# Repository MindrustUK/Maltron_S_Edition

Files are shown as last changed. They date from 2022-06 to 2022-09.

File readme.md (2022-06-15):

# Maltron - S Edition

** THIS IS A WORK IN PROGRESS, EXPECT BUGS AND DEBUGGING OPTIONS TO BE SET**

This repository contains historical documentation and instructions for creating a STM32 Black Pill based Keyboard
controller for Maltron Right Handed Keyboards running the open source QMK Firmware.

I'm hoping to get the new firmware into QMK mainstream at some stage in the future.

If anyone has any feedback please feel free to open an issue on the GitHub tracker, and I'll respond to you when I can.

All files can be found in their respective subdirectories as follows:
- EasyEDA Outfiles: This contains; Easy EDA, Altium, Gerber and SVG outputs of the Schematic and PCB design for the 
Maltron compatible STM32 Based controller.
- QMK Firmware: The QMK Firmware for the Maltron S Edition keyboard. This is a work in progress and not final yet.
- FreeCAD - PCB Stand Offs: This contains some simple PCB Stand-Offs that can be glued to the existing Maltron case's
baseplate. These are designed to use M2 self taping wood screws.
- Pictures: Pictures of the build for the historical document.

## Circuit notes
- All diodes are 1n4148
- Resistors for LEDS (R3-R10) are 100 Ohm
- Resistors for I2C Pull up (R1, R2) are 10K Ohm

## FreeCAD Notes
- Screws for PCB mounting are M2 Self Tapping Wood screws - Pan Head type.

## QMK Firmware Notes
- Large portions of this code were adapted from
[https://github.com/zvecr/qmk_firmware/blob/feature/ergodone_ctpc/keyboards/ktec/ergodone/matrix.c](https://github.com/zvecr/qmk_firmware/blob/feature/ergodone_ctpc/keyboards/ktec/ergodone/matrix.c)
so all credit to this user for their work. This helped me massively with the MCP23018 I/O Expander.
- Setup QMK as per [https://docs.qmk.fm/#/newbs_getting_started](https://docs.qmk.fm/#/newbs_getting_started)
- copy *mindrustuk* from the QMK Firmware directory to *keyboards/* in the QMK installation path
- NOTE: On first flash the STM32 Black Pill will need to be put into bootloader mode, do this by:
  - pushing and holding the `reset` button
  - then hold the `boot0` button
  - release the `reset` button
  - then release the `boot0` button. 
  - The device should now be in the bootloader mode ready to be flashed.
- compile using the following command ```qmk compile -kb mindrustuk/maltron_s_edition -km default```
- flash with the following command ```qmk flash -kb mindrustuk/maltron_s_edition -km default```
- Note: The firmware has `bootmagic` enabled. Any subsequent need to flash can be done by holding the `esc` key while
plugging in the keyboard, doing this will force the keyboard into bootloader mode on boot.
- Note: Debugging is currently enabled on this keyboard and output can be seen with ```qmk console -l```

## Miscellaneous Keyboard details
- The keyboard has four layers, these have not been fully implemented yet:
  - Layer 1: English
  - Layer 2: Numeric Pad
  - Layer 3: German
  - Layer 4: Media Keys

- Attempts have been made to preserve / replicate "one shot" behaviour and sticky keys on the Maltron keyboard. Please
see the source code for details on these.

- Bootmagic is set to use the escape key to flash firmware on boot, this could be re-mapped if desired:
  ```
  // Hold ESC on start up to boot into bootloader mode
  #define BOOTMAGIC_LITE_ROW 0
  #define BOOTMAGIC_LITE_COLUMN 14
  ```

## History
For a history of how this project started and evolved please see [history.md](history.md)

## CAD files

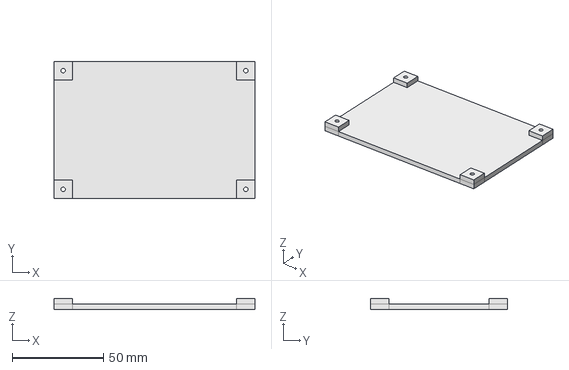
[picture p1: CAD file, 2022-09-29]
Controller Mount Mk2.FCStd
110.0 x 75.0 x 6.00 mm

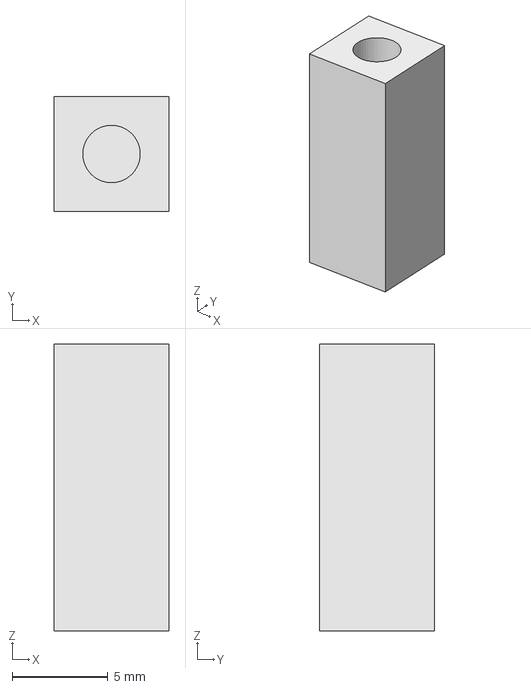
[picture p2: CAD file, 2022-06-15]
FreeCad - PCB Stand Offs/Maltron PCB Mounts.FCStd
6.00 x 6.00 x 15.0 mm

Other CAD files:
Controller Mount Mk2-Cut003.stl

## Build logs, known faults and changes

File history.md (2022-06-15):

# Maltron - S Edition - The history

This project started when a hemiplegic user with a few different versions / variants of the Maltron Single handed 
(right side) keyboard, was having trouble with slightly different layouts across the keyboards they used at various
sites.

Some of these were the current (as of time of writing) keyboards sold by Maltron, Others were older PS/2 style units.

The user wanted to achieve as close parity between all units in terms of the keyboard's layout. To this end, the older
PS/2 Keyboards would be converted to USB using the [QMK Firmware](https://qmk.fm/) to cover many of the features (sticky
keys, layers etc.) that were built into these units.  This would also mean the keymap could be changed to bring them
into line with the current layout for the keyboard found here:
[https://www.maltron.com/united-kingdom.html](https://www.maltron.com/united-kingdom.html), specifically the
**RS10N1X-UK** model.

When asking for assistance on Reddit in understanding how QMK worked with IO Expanders, a user asked that I document the
process, and thus this repository was created.

This repository contains the following materials:
- Docuemtnation on the process
- Circuit Diagrams
- Gerber files
- Easy EDA files
- The Maltron S Edition specific files for generating a compatible QMK Firmware.

A comparison of two of the keyboard types can be seen in the following pictures:

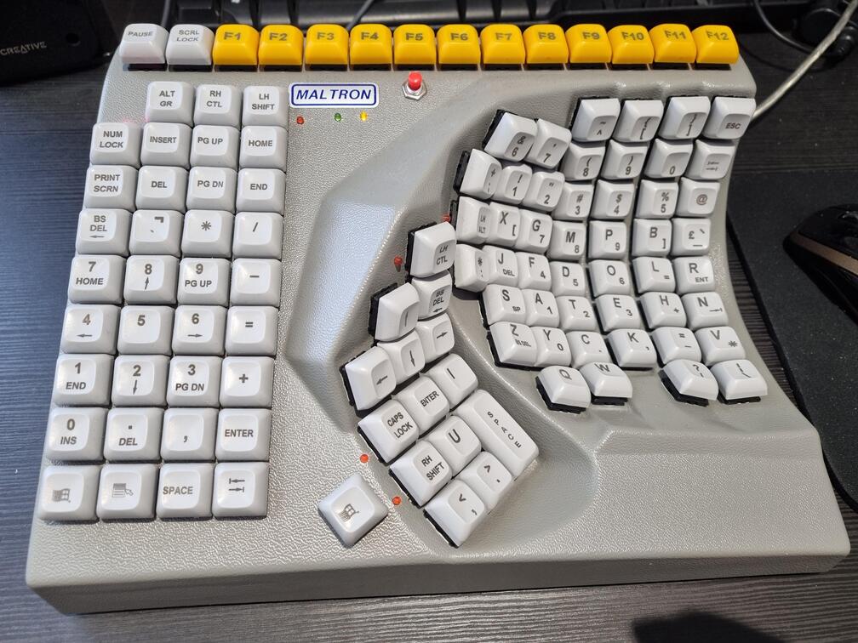
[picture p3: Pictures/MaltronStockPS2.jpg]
Maltron Stock PS2 Keyboard

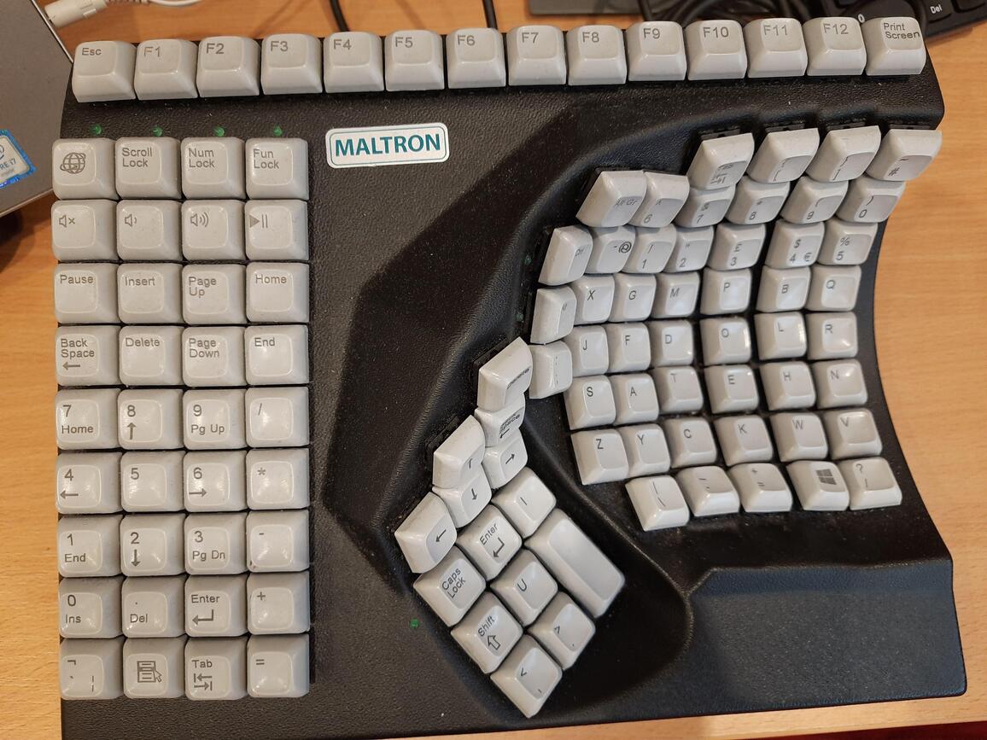
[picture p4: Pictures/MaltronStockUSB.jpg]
Maltron Stock USB Keyboard


## The process

The first step was to understand the anatomy of they device, on the PS/2 units that I'd be working on some searching
revealed the matrix in use was an 8 row, 16 column matrix, further use of a multi meter and physical inspection showed
8 leds in use with 8 diodes on the rows for anti ghosting.

As I wasn't confident at this stage and wanted a back out plan before committing I decided to remove the factory IDC
transition connector and replace it with a 34 pin IDC connector allowing for controller replacements in the future along
with easy prototyping and most of all a way to roll back if anything proved to be beyond reasonable.

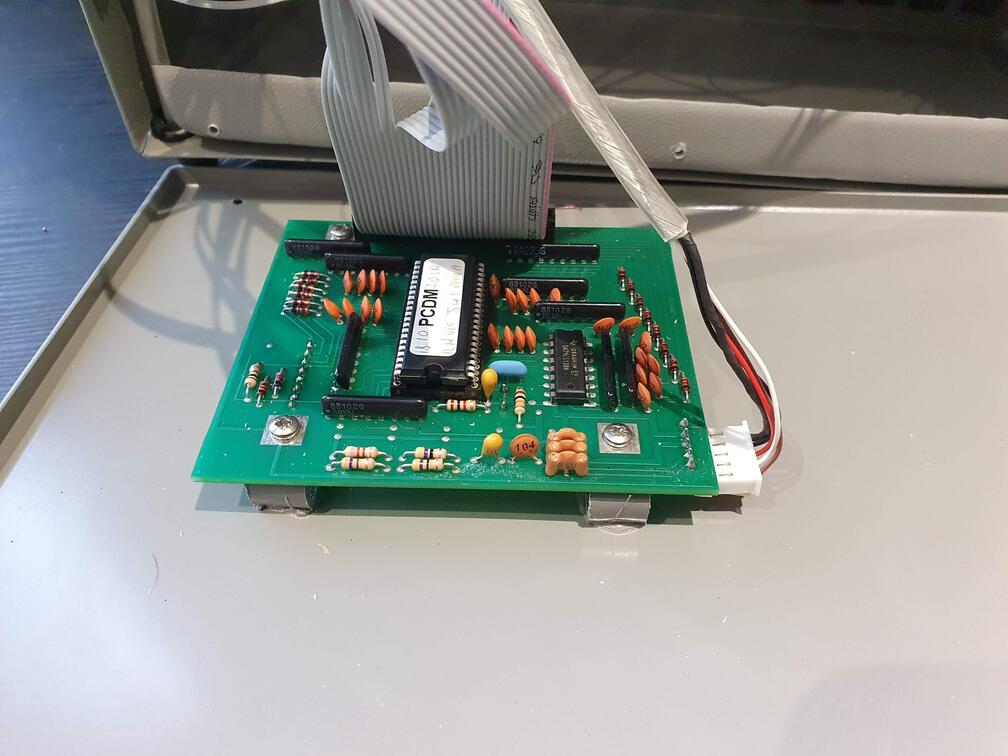
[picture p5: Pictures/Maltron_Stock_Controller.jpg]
Maltron Stock Controller


The next step was to select a controller and start experimenting. I had faith in the QMK project as I had a friend who
had been raving about his custom-built keyboards for a while. I had 32 pins worth of Input / Output to deal with.
The larger Teensy series controllers proved expensive and hard to source in the UK and also offered less I/O than
competitors. The Raspberry Pi Pico was also evaluated and passed on for reasons I can't quite remember. I then found the
STM 32 - Black Pill module. This had USB-C, plenty of I/O, loads of memory and more than enough CPU power and
importantly was supported by qmk. However, I would shortly find out much of the I/O was unusable.

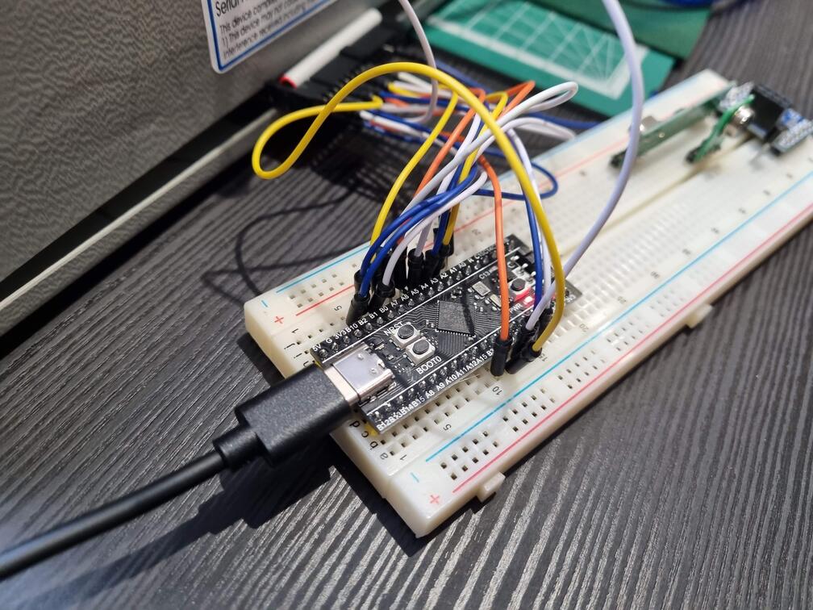
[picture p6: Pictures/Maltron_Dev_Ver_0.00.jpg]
Maltron S Edition Dev 0.00 Controller


Early test with the QMK firmware was to build the simplest keyboard possible and get the matrix running. I managed to
get all rows and columns working and then started getting strange behaviour as I expanded, such as the controller not
starting, Errors with flashing and so on. I discovered after more study of documentation and searching Reddit that;
pins A9, A11 and A12 are all attached to USB, A10 can be used as an input but requires a pull-up resistor and B2 is a
reserved for use in the bootloader functionality. After some research and understanding the attributes of each of these
pins I realised no matter what I did on this module, I'd have to add an I/O expander.

The I2C bus is well known and widely supported, also thanks to some friendly pointers on Reddit and investigating the
Ergodox keyboard documentation and QMK Firmware, I found that the Microchip MCP23018 would fit my use case.

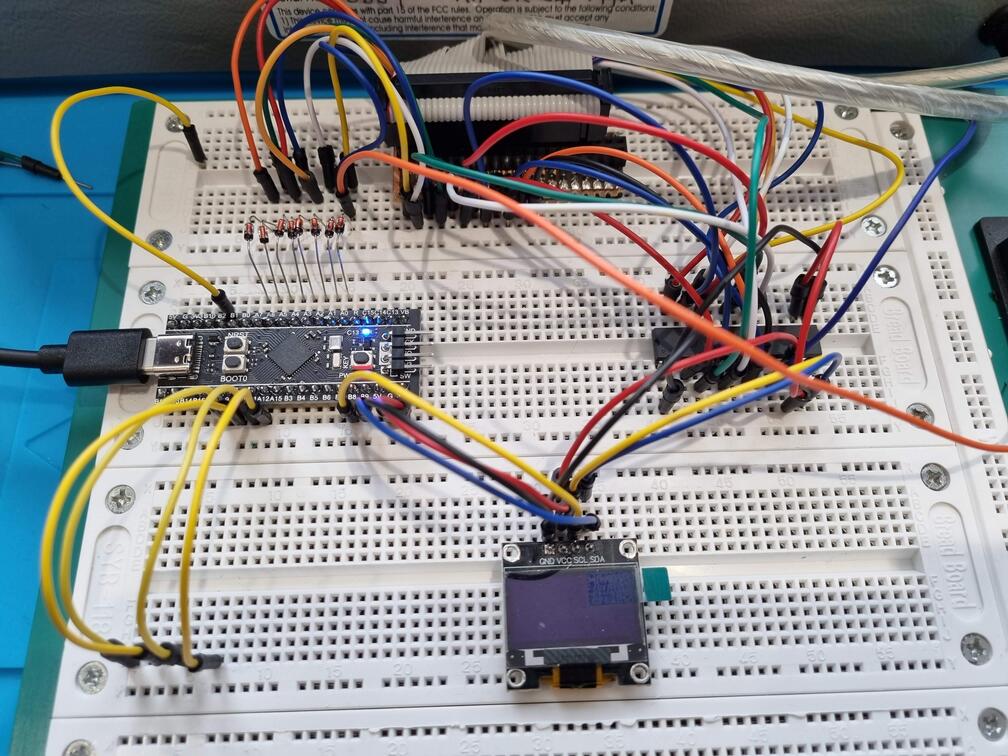
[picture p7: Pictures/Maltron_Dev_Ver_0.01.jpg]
Maltron S Edition Dev 0.01 Controller


The next challenge would be software, thankfully I got lucky and during my prototyping, the QMK project matured and the
I2C support for the MCP23018 became natively available. I also found someone who had ported their version of the
firmware to the native driver:
[ergodone](https://github.com/zvecr/qmk_firmware/blob/feature/ergodone_ctpc/keyboards/ktec/ergodone/matrix.c)
I also added a SSD1306 OLED to the project as a temporary measure to give me some easy visual output as I continued 
work on getting the I2C support added. After coming to understand the firmware, adding debugging and generally maturing
the project, I removed the OLED support. This could be added back at anytime should anyone desire it.

I now had an I2C expander on all the columns of the keyboard, the LEDs and rows being driven from the STM32 Black Pill
controller and a basic keymap working. I now moved from Breadboard Development to a Soldered Prototype.

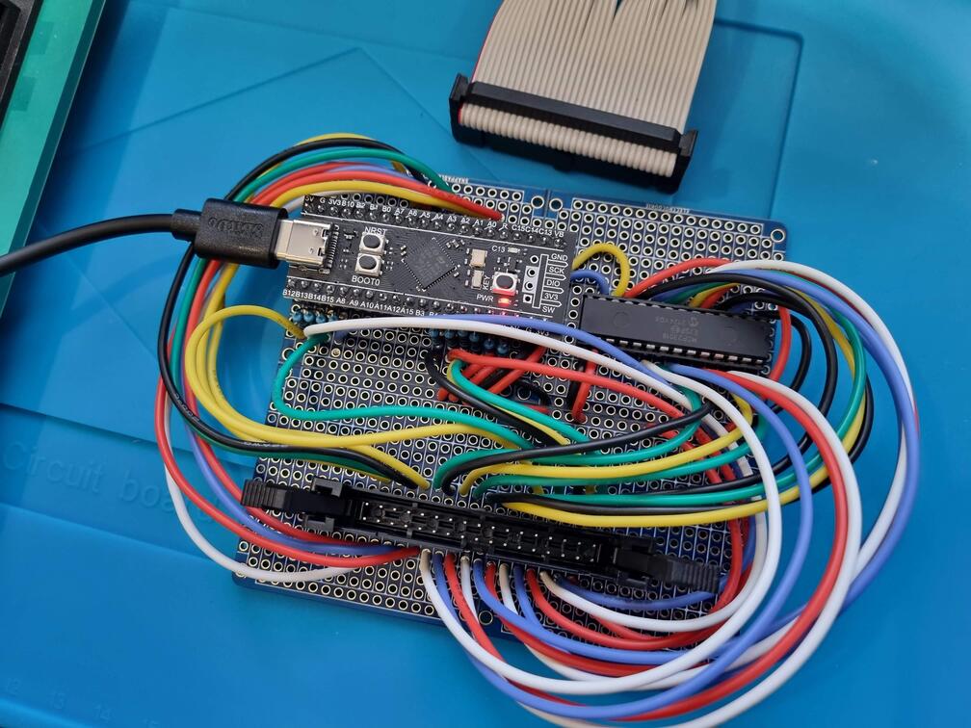
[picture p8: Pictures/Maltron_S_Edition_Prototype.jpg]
Maltron S Edition Prototype Controller


After an evening with the soldering iron I had a prototype version of the controller. More revisions of the software, 
more tweaking, getting sticky keys working, and adding layer support was done. Shortly after this process it was time to
move to the "production" version of the design. And after an amazingly quick session in [EasyEDA](https://easyeda.com/),
I had the following diagram:

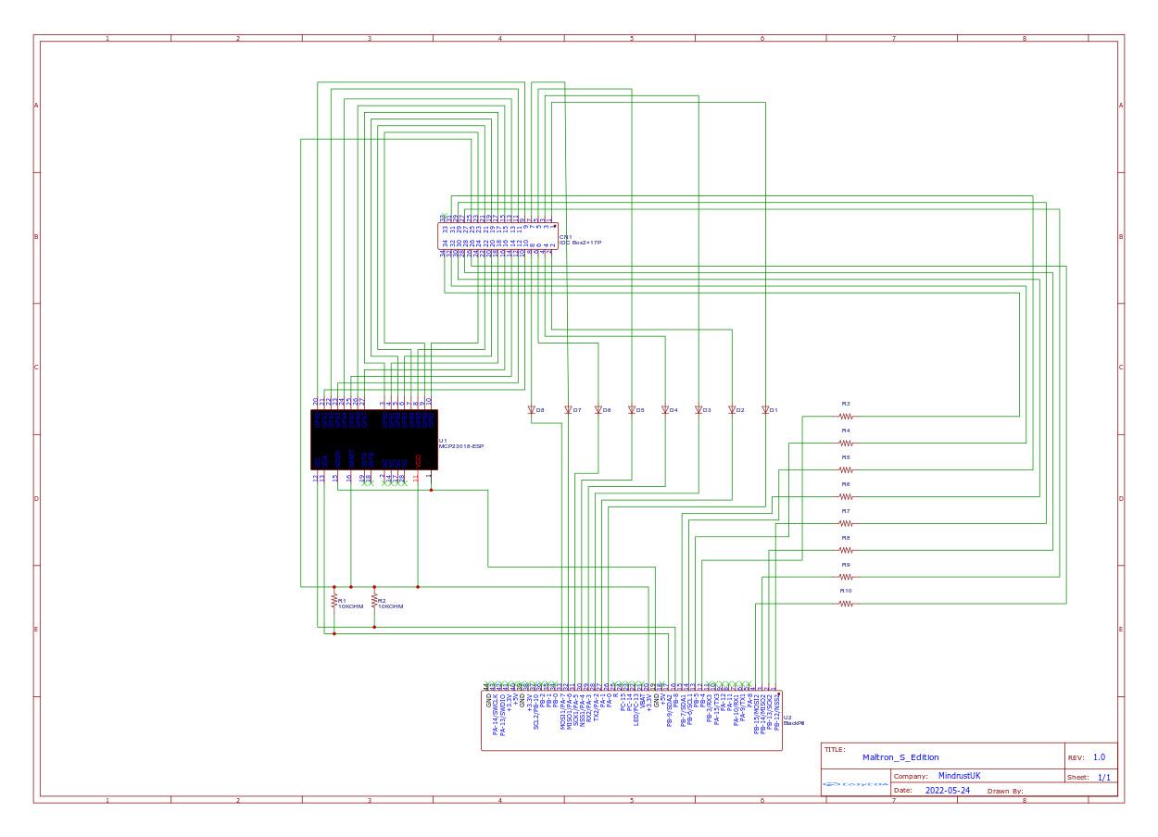
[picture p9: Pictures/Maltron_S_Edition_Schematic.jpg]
Maltron S Edition Schematic


I then ordered five prints of the board from [JLC PCB](https://jlcpcb.com/) exporting from EasyEDA straight into their
PCB CAD software, the boards arrived SUPER quickly as below:

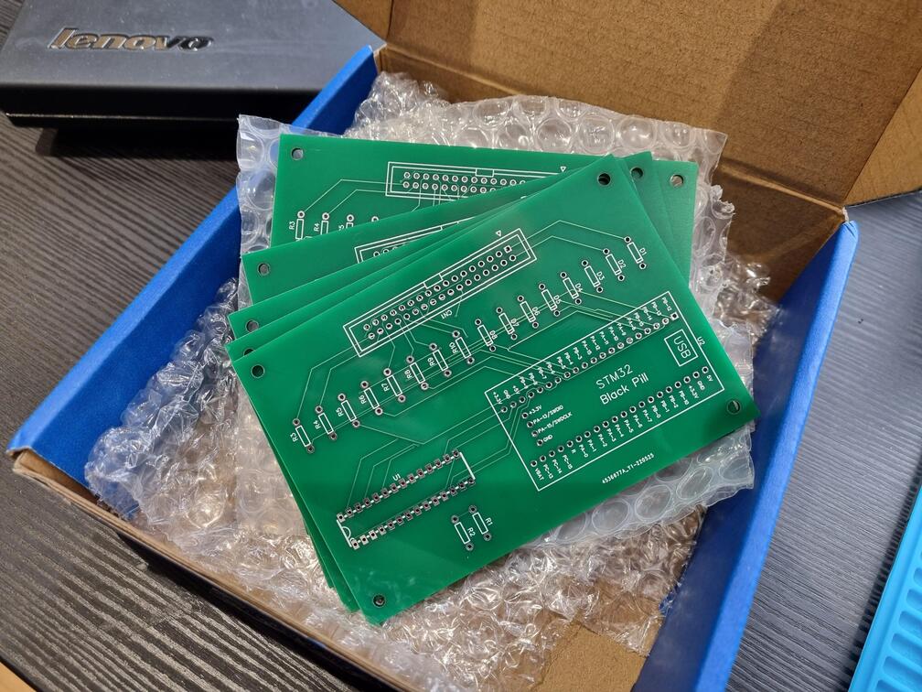
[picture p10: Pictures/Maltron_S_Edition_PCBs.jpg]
Maltron S Edition PCBs


Some assembly later and I had the following:

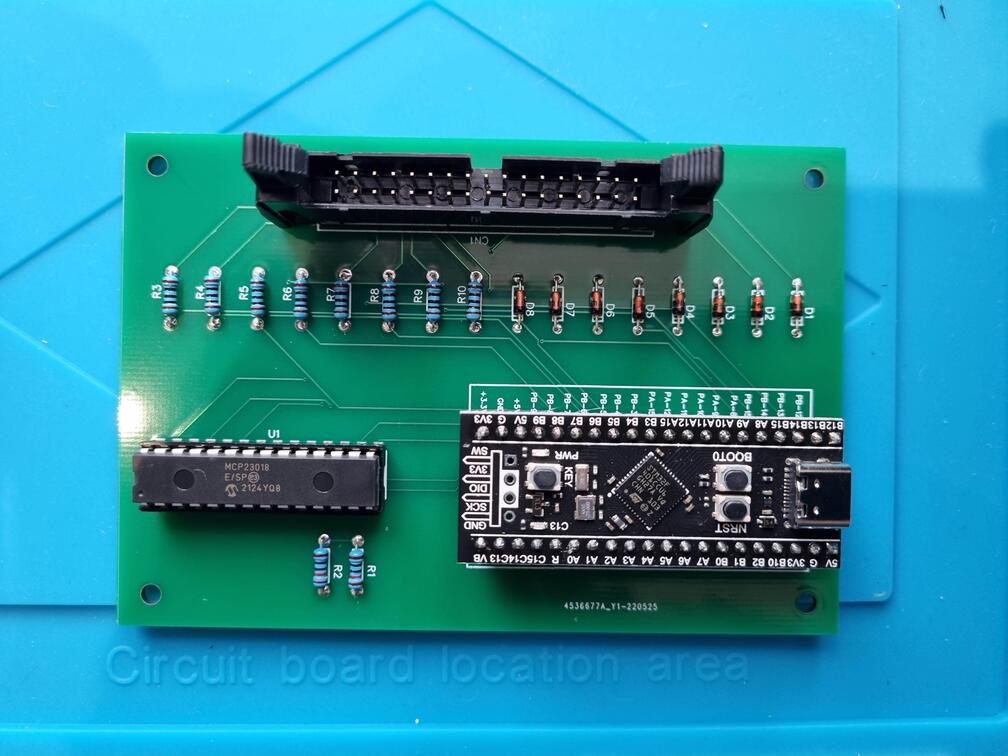
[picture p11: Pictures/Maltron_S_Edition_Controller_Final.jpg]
Maltron_S_Edition_Controller_Final


A quick test and everything works as expected. After testing and reviewing with the user, they wanted to purchase key 
caps from Maltron to match up the available keys in the closest possible way.

The next few jobs were a bit of 3d printing; to provide new stand-offs, seal up holes in the original unit and to
provide a re-enforcement where required. A USB-C panel mount connector was also added to keep everything socket and
modular for easy maintenance. This also helped the user as having a removable cable is a great benefit for them when
traveling and having to fit the Keyboard into luggage.

And finally a shot of testing before final assembly.

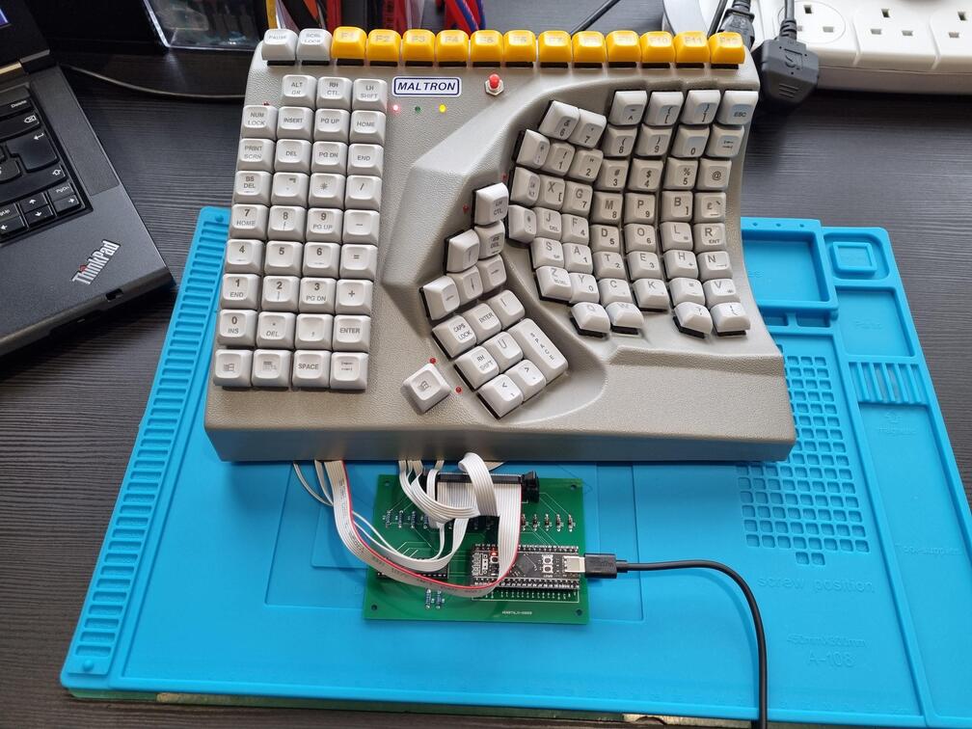
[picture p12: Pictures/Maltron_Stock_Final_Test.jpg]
Maltron_S_Edition_Final Test


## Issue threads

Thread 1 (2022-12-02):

QMK support for modded two-handed maltron keyborads does exist already.

dvdkhlng, 2022-12-02:
Hi,

I recently was faced with a similar problem and hacked my Maltron keyboard to work with QMK:

https://github.com/dvdkhlng/qmk_firmware_dqz11n1g/tree/master/keyboards/handwired/dqz11n1g

Upstream QMK did accept a pull request with my firmware changes, so this specific keyboard is now also listed in the online QMK keyboard configurator:

https://config.qmk.fm/#/handwired/dqz11n1g/LAYOUT

It looks like your right-handed maltron's controller also uses a 17x2 DIL connector, so there might be some chance to come up with a controller board that supports both Maltrons.

I did not succeed in sourcing black-pill controllers so had to base my work on an Arduino pro-micro controller.

cheers,

David

MindrustUK, 2022-12-02:
In theory it should be possible to make a generic board that will work across all the current PCD Maltron keyboards. It looks like all but one pin is the same. I'd still opt to use the MCP IO Expanders again as these can be reconfigured in software on the fly leaving more versatility. Thanks for sharing your work, hopefully this will be useful to others modifying these Maltron keyboards.

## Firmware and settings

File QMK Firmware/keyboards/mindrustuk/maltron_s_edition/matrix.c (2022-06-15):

// Copyright 2022 QMK
// SPDX-License-Identifier: GPL-2.0-or-later

#include "gpio.h"
#include "matrix.h"
#include "mcp23018.h"
#include "util.h"
#include "wait.h"
#include "debug.h"

// Pull ADDR (Pin 15) to ground for an easy 0x20
// See MCP23018 documentation for how to set alternate addresses
#define I2C_ADDR 0x20

// Set the error counter to 0
static uint8_t mcp23018_errors = 0;

static void led_output_pins_init(void) {
    // Blink all LEDs twice on boot.

    // Set output pins
    setPinOutput(B4);                       // initialize B4 for LED
    setPinOutput(B5);                       // initialize B5 for LED
    setPinOutput(B6);                       // initialize B6 for LED
    setPinOutput(B7);                       // initialize B7 for LED
    setPinOutput(B12);                      // initialize B12 for LED
    setPinOutput(B13);                      // initialize B13 for LED
    setPinOutput(B14);                      // initialize B14 for LED
    setPinOutput(B15);                      // initialize B15 for LED
    
    // Debug message
    uprintf("Blinking all leds\n");

    // Attempt to blink LEDs twice
    writePinLow(B4);
    writePinLow(B5);
    writePinLow(B6);
    writePinLow(B7);
    writePinLow(B12);
    writePinLow(B13);
    writePinLow(B14);
    writePinLow(B15);
    wait_ms(250);
    writePinHigh(B4);
    writePinHigh(B5);
    writePinHigh(B6);
    writePinHigh(B7);
    writePinHigh(B12);
    writePinHigh(B13);
    writePinHigh(B14);
    writePinHigh(B15);
    wait_ms(250);
    writePinLow(B4);
    writePinLow(B5);
    writePinLow(B6);
    writePinLow(B7);
    writePinLow(B12);
    writePinLow(B13);
    writePinLow(B14);
    writePinLow(B15);
    wait_ms(250);
    writePinHigh(B4);
    writePinHigh(B5);
    writePinHigh(B6);
    writePinHigh(B7);
    writePinHigh(B12);
    writePinHigh(B13);
    writePinHigh(B14);
    writePinHigh(B15);
    wait_ms(250);
}

static void expander_init(void) {
    mcp23018_init(I2C_ADDR);
}

static void expander_init_cols(void) {
    mcp23018_errors += !mcp23018_set_config(I2C_ADDR, mcp23018_PORTA, ALL_INPUT);
    mcp23018_errors += !mcp23018_set_config(I2C_ADDR, mcp23018_PORTB, ALL_INPUT);
}

static matrix_row_t expander_read_row(void) {
    if (mcp23018_errors) {
        return 0;
    }

    uint8_t ret_a = 0xFF;
    uint8_t ret_b = 0xFF;
    uint16_t ret = 0x00;
    mcp23018_errors += !mcp23018_readPins(I2C_ADDR, mcp23018_PORTA, &ret_a);
    mcp23018_errors += !mcp23018_readPins(I2C_ADDR, mcp23018_PORTB, &ret_b);

    ret_a = (~ret_a);
    ret_b = (~ret_b);
    ret = ret_a + (((uint16_t)ret_b) << 8);

    return (uint16_t)ret;
}

static void expander_scan(void) {
    if (!mcp23018_errors) {
        return;
    }

    static uint16_t mcp23018_reset_loop = 0;
    if (++mcp23018_reset_loop > 0x1FFF) {
        // tuned to about 5s given the current scan rate
        dprintf("trying to reset mcp23018\n");
        uprintf("trying to reset mcp23018\n");
        mcp23018_reset_loop = 0;
        mcp23018_errors     = 0;
        // expander_unselect_rows();
        expander_init_cols();
    }
}

static void init_cols(void) {
    // STM32 BlackPill - We don't want to read any colums using the onboard chip.
    // Expander
    expander_init_cols();
}

static matrix_row_t read_cols(void) {
    return expander_read_row();
}

static void unselect_rows(void) {
    // STM32 BlackPill
    setPinInput(A0);
    setPinInput(A1);
    setPinInput(A2);
    setPinInput(A3);
    setPinInput(A4);
    setPinInput(A5);
    setPinInput(A6);
    setPinInput(A7);
    writePinLow(A0);
    writePinLow(A1);
    writePinLow(A2);
    writePinLow(A3);
    writePinLow(A4);
    writePinLow(A5);
    writePinLow(A6);
    writePinLow(A7);
}

static void unselect_row(uint8_t row) {
    // STM32 Black Pill
    switch (row) {
        case 0:
            setPinInput(A0);
            writePinLow(A0);
            break;
        case 1:
            setPinInput(A1);
            writePinLow(A1);
            break;
        case 2:
            setPinInput(A2);
            writePinLow(A2);
            break;
        case 3:
            setPinInput(A3);
            writePinLow(A3);
            break;
        case 4:
            setPinInput(A4);
            writePinLow(A4);
            break;
        case 5:
            setPinInput(A5);
            writePinLow(A5);
            break;
        case 6:
            setPinInput(A6);
            writePinLow(A6);
            break;
        case 7:
            setPinInput(A7);
            writePinLow(A7);
            break;
    }
}

static void select_row(uint8_t row) {
    // STM32 Black Pill
    switch (row) {
        case 0:
            setPinOutput(A0);
            writePinLow(A0);
            break;
        case 1:
            setPinOutput(A1);
            writePinLow(A1);
            break;
        case 2:
            setPinOutput(A2);
            writePinLow(A2);
            break;
        case 3:
            setPinOutput(A3);
            writePinLow(A3);
            break;
        case 4:
            setPinOutput(A4);
            writePinLow(A4);
            break;
        case 5:
            setPinOutput(A5);
            writePinLow(A5);
            break;
        case 6:
            setPinOutput(A6);
            writePinLow(A6);
            break;
        case 7:
            setPinOutput(A7);
            writePinLow(A7);
            break;
    }
}

static bool read_cols_on_row(matrix_row_t current_matrix[], uint8_t current_row) {
    // Store last value of row prior to reading
    matrix_row_t last_row_value = current_matrix[current_row];

    // Clear data in matrix row
    current_matrix[current_row] = 0;

    // Select row and wait for row selection to stabilize
    select_row(current_row);
    // Skip the wait_us(30); as i2c is slow enough to debounce the io changes

    current_matrix[current_row] = read_cols();

    unselect_row(current_row);

    return (last_row_value != current_matrix[current_row]);
}

void matrix_init_custom(void) {
    led_output_pins_init();

    expander_init();

    unselect_rows();
    init_cols();
}

bool matrix_scan_custom(matrix_row_t current_matrix[]) {
    expander_scan();

    bool changed = false;
    for (uint8_t current_row = 0; current_row < MATRIX_ROWS; current_row++) {
        changed |= read_cols_on_row(current_matrix, current_row);
    }
    return changed;
}
